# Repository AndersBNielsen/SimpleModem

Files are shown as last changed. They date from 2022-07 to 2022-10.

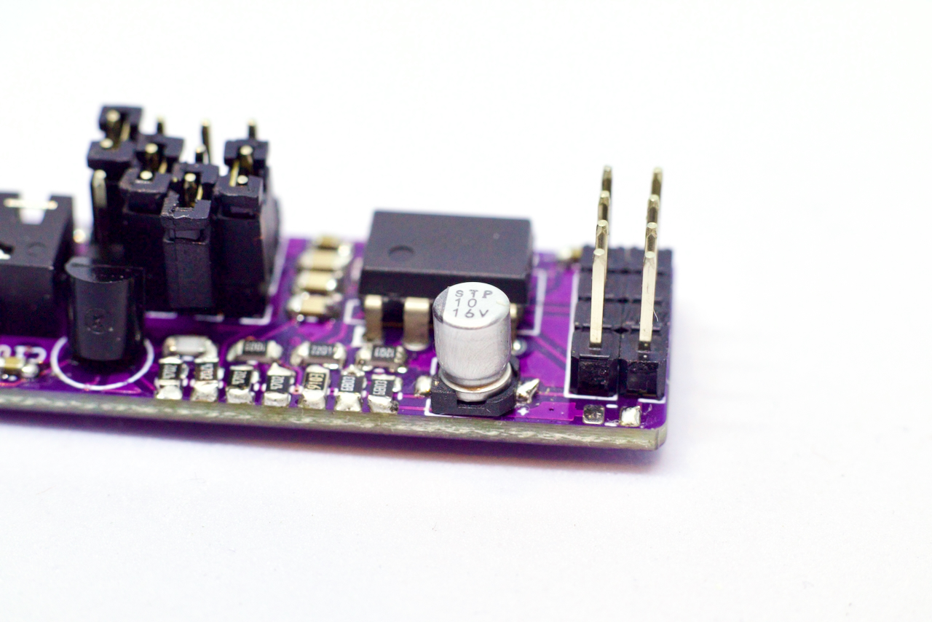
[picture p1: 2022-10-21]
Photos/Resized/IMG_4693.jpeg

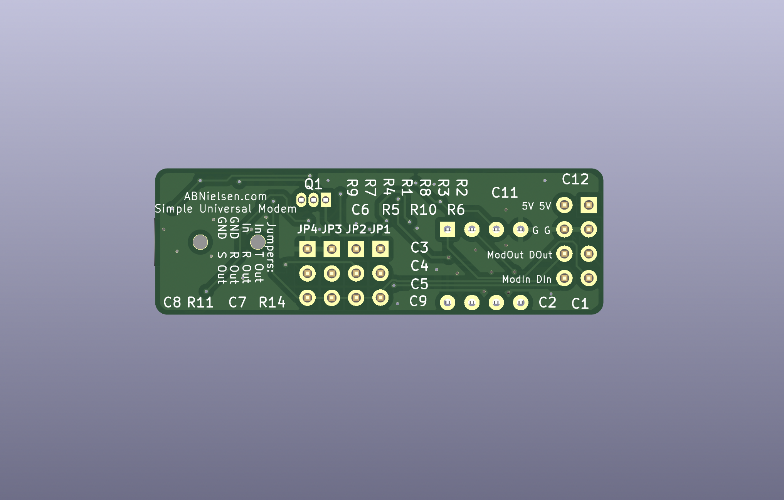
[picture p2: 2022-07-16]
ModemBack.png

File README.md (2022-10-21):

# SimpleModem
Simple Universal Modem

Check out the project on https://hackaday.io/project/186309-simple-universal-modem
Also check out the video demo: https://www.youtube.com/watch?v=k8hlYr6N3Ls

If you are looking for software to use with this, you should check out my 6502 Single Board Computer repo: https://github.com/AndersBNielsen/abn6502

TX:
The component values are configured to expect a 1200/2400Hz FSK modulated square wave on the DataOut(DOut on the silkscreen) pin. This signal is band pass filtered to make a 1V peak to peak sine wave that is output on the ModOut pin.

RX:
The ModIn pin expects an FSK modulated sine wave(Audio). 1V peak to peak recommended input. Output on the DataIn(DIn on the silkscreen) is a 5V square wave that can be used to decode the FSK decoding using an active low interrupt pin. The ModIn pin is not filtered but capacitively coupled using a 100nF cap. It's been tested using computer audio and tape with 1200/2400Hz FSK.

The TRRS jack's poles are meant to be configured using J1-J4 jumpers. An "iPhone" TRRS cable has the pinout right, left, GND, microphone - "Android" TRRS cable usually is right, left, microphone, GND. A standard TRS cable plugged into this would be right, left, GND, GND - for my 1972 tape deck I used a 3.5mm -> RCA/Phono cable and had it configured for ModIn, Modout, GND, GND.

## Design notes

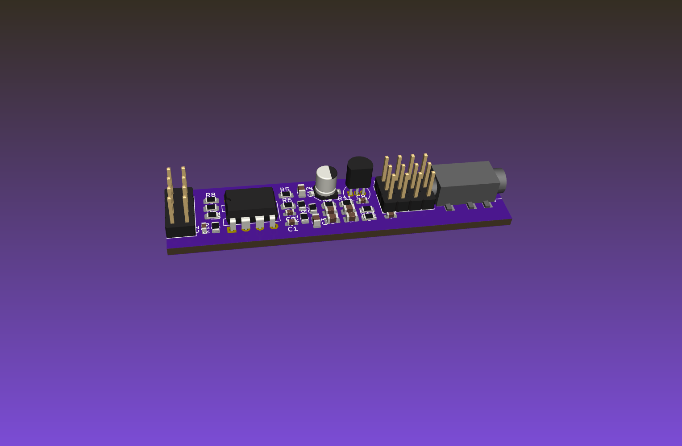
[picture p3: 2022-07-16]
InitialSketch.png

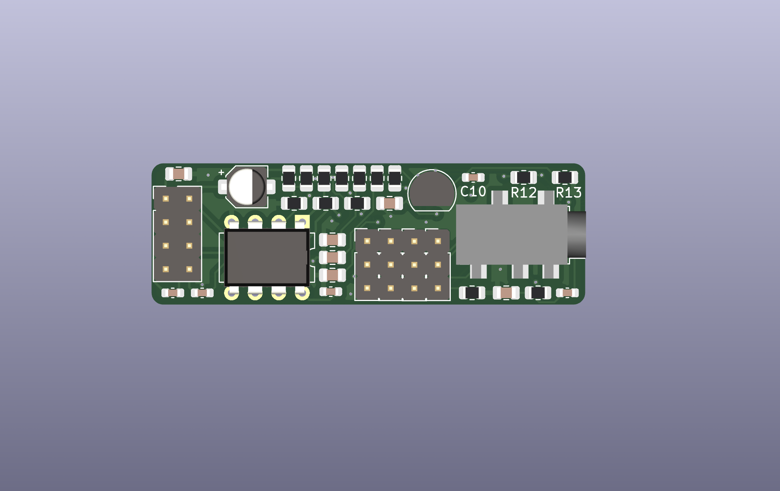
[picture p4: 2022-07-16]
ModemFront.png

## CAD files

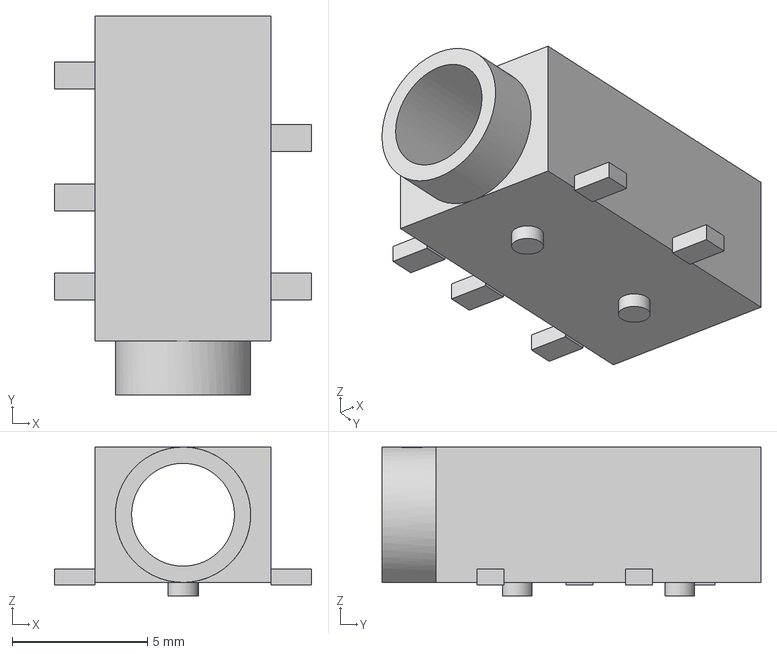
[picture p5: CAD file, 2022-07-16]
Jack-audio-3.5mm(PJ-327F-5A).step
9.50 x 14.0 x 5.50 mm

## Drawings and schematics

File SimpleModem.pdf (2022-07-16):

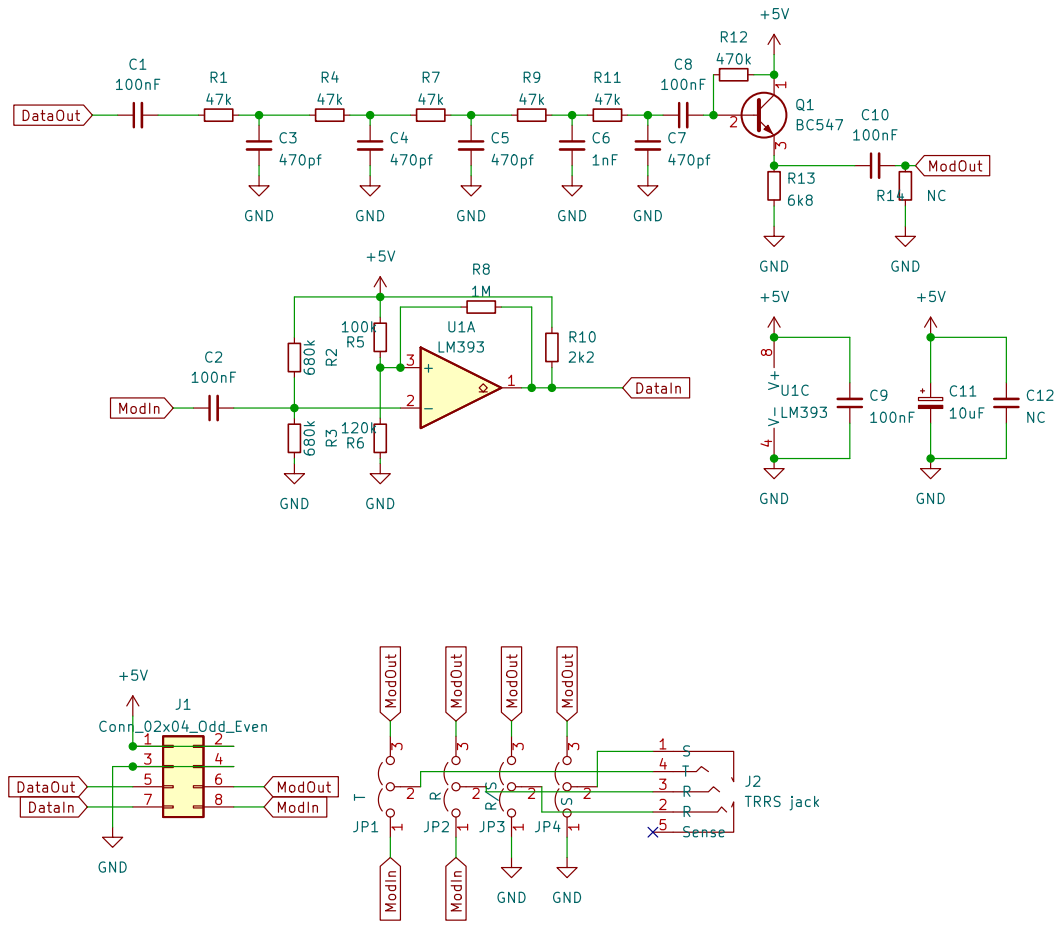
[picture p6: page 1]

https://creativecommons.org/licenses/by-nc/4.0/
License: Attribution-NonCommercial 4.0 International (CC BY-NC 4.0)
File: SimpleModem.kicad_sch Sheet: / Copyright: Anders B. Nielsen

Id: 1/1 Title: Simple Universal Modem

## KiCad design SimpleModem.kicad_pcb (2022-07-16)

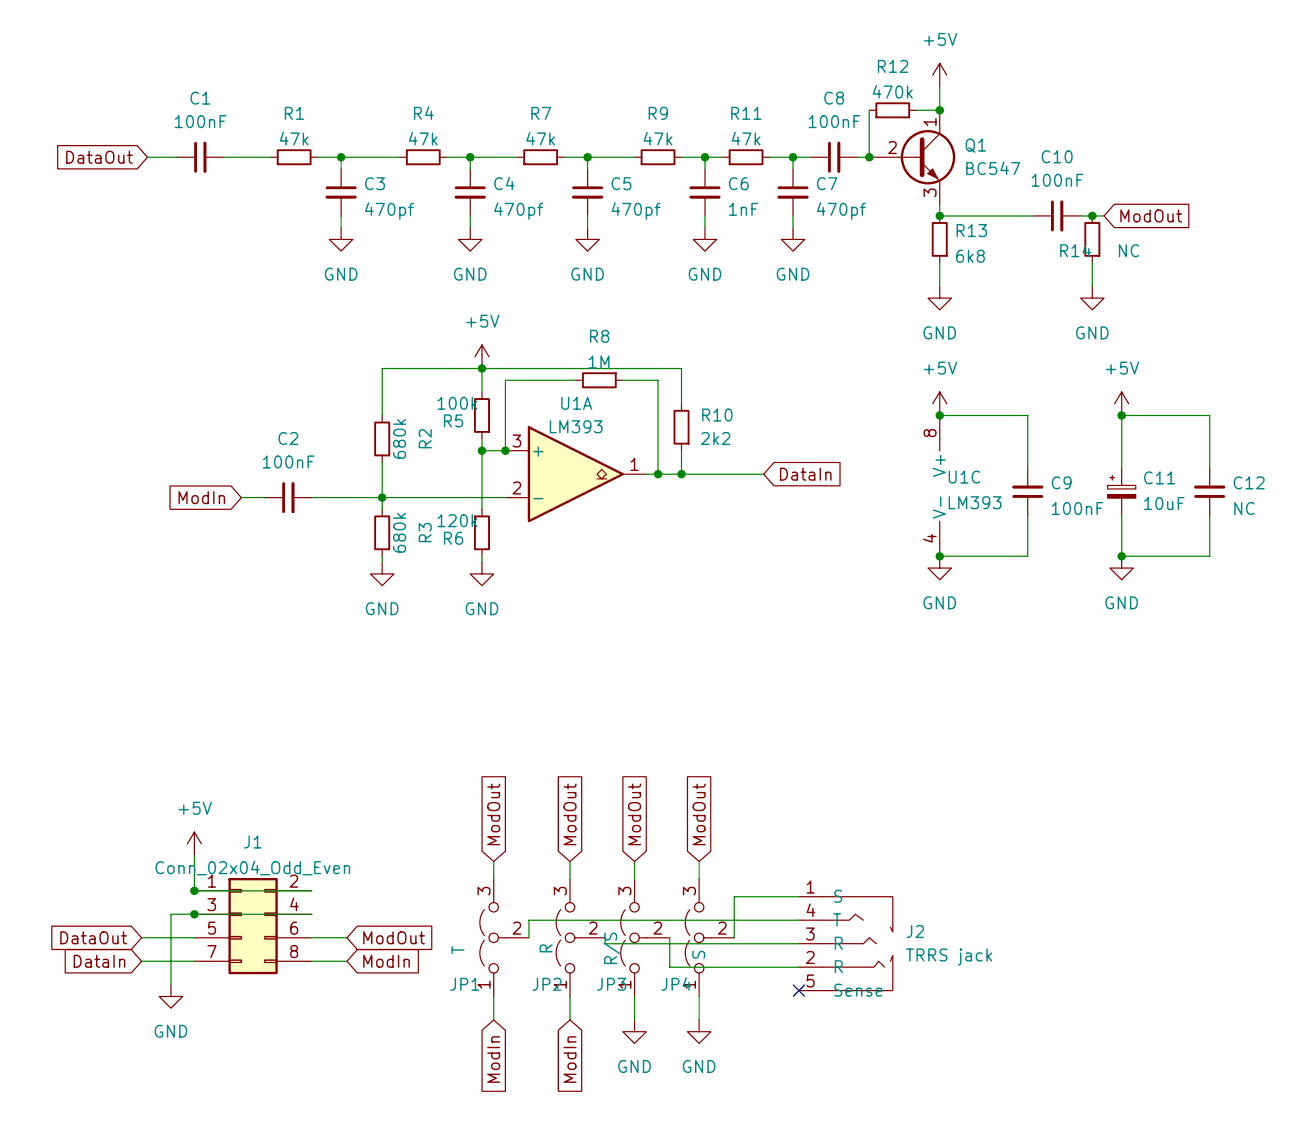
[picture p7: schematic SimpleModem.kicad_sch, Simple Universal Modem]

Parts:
C1, C2, C8, C9, C10: 100nF; C_0603_1608Metric
C3, C4, C5, C7: 470pf; C_0805_2012Metric
C6: 1nF; C_0805_2012Metric
C11: 10uF; CP_Elec_4x5.3
C12: NC; C_0805_2012Metric
J1: Conn_02x04_Odd_Even; PinHeader_2x04_P2.54mm_Vertical
J2: TRRS jack; Jack_3.5mm_4Poles_5pins_SMD_ABN
JP1: T; PinHeader_1x03_P2.54mm_Vertical
JP2: R; PinHeader_1x03_P2.54mm_Vertical
JP3: R/S; PinHeader_1x03_P2.54mm_Vertical
JP4: S; PinHeader_1x03_P2.54mm_Vertical
Q1: BC547; TO-92_Inline
R1, R4, R7, R9, R11: 47k; R_0805_2012Metric
R2, R3: 680k; R_0805_2012Metric
R5: 100k; R_0805_2012Metric
R6: 120k; R_0805_2012Metric
R8: 1M; R_0805_2012Metric
R10: 2k2; R_0805_2012Metric
R12: 470k; R_0805_2012Metric
R13: 6k8; R_0805_2012Metric
R14: NC; R_0805_2012Metric
U1: LM393; DIP-8_W7.62mm

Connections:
+5V: C9.2, C11.1, C12.2, J1.1, J1.2, Q1.1 (C), R2.2, R5.2, R10.2, R12.2, U1.8 (V+)
DataIn: J1.7, R8.1, R10.1, U1.1
DataOut: C1.1, J1.5
GND: C3.2, C4.2, C5.2, C6.2, C7.2, C9.1, C11.2, C12.1, J1.3, J1.4, JP3.1 (A), JP4.1 (A), R3.1, R6.2, R13.1, R14.1, U1.4 (V-)
ModIn: C2.1, J1.8, JP1.1 (A), JP2.1 (A)
ModOut: C10.2, J1.6, JP1.3 (B), JP2.3 (B), JP3.3 (B), JP4.3 (B), R14.2
unnamed: C1.2, R1.1
unnamed: C2.2, R2.1, R3.2, U1.2 (-)
unnamed: C3.1, R1.2, R4.1
unnamed: C4.1, R4.2, R7.1
unnamed: C5.1, R7.2, R9.1
unnamed: C6.1, R9.2, R11.1
unnamed: C7.1, C8.1, R11.2
unnamed: C8.2, Q1.2 (B), R12.1
unnamed: C10.1, Q1.3 (E), R13.2
unnamed: J2.1 (S), JP4.2 (C)
unnamed: J2.2 (R), JP3.2 (C)
unnamed: J2.3 (R), JP2.2 (C)
unnamed: J2.4 (T), JP1.2 (C)
unnamed: R5.1, R6.1, R8.2, U1.3 (+)

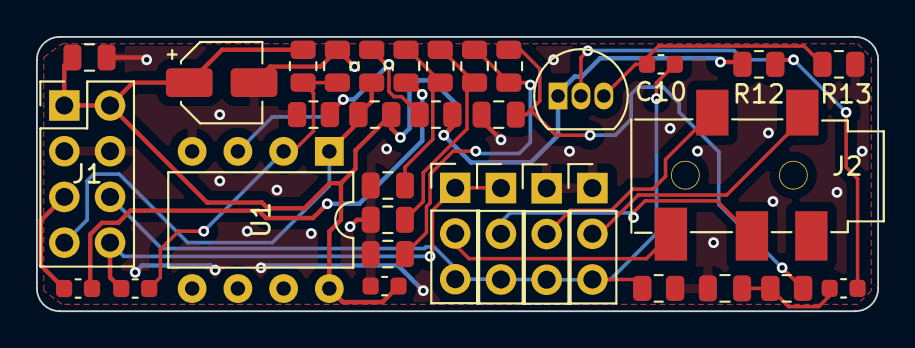
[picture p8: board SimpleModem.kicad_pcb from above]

Board: 2 copper layers, 46.7 x 15.2 mm, 34 parts (0 on the bottom side), 20 nets.

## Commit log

2022-07-16 Initial release
    [Jack-audio-3.5mm(PJ-327F-5A).step, SimpleModem.kicad_pcb, SimpleModem.kicad_sch]
2022-07-16 Gerbers, schematics and screenshots
2022-10-18 Gerbers tested - working as intended
